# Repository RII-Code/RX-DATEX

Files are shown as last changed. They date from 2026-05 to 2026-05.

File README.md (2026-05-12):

# RX-DATEX (DATA EXCHANGE)

Perangkat IoT industrial yang berfungsi sebagai sistem gateway dan data exchange untuk komunikasi, monitoring, dan pertukaran data antar perangkat industri.

## Fitur

- Gateway Modbus RTU ↔ TCP/IP
- Pengirim data telemetry melalui jaringan 4G LTE
- Sistem monitoring device industri
- Data logger dan remote monitoring
- MQTT / HTTP data exchange
- Remote access dan konfigurasi perangkat

---

## Author

Ruang Industri Indonesia  
Industrial Automation & Robotics

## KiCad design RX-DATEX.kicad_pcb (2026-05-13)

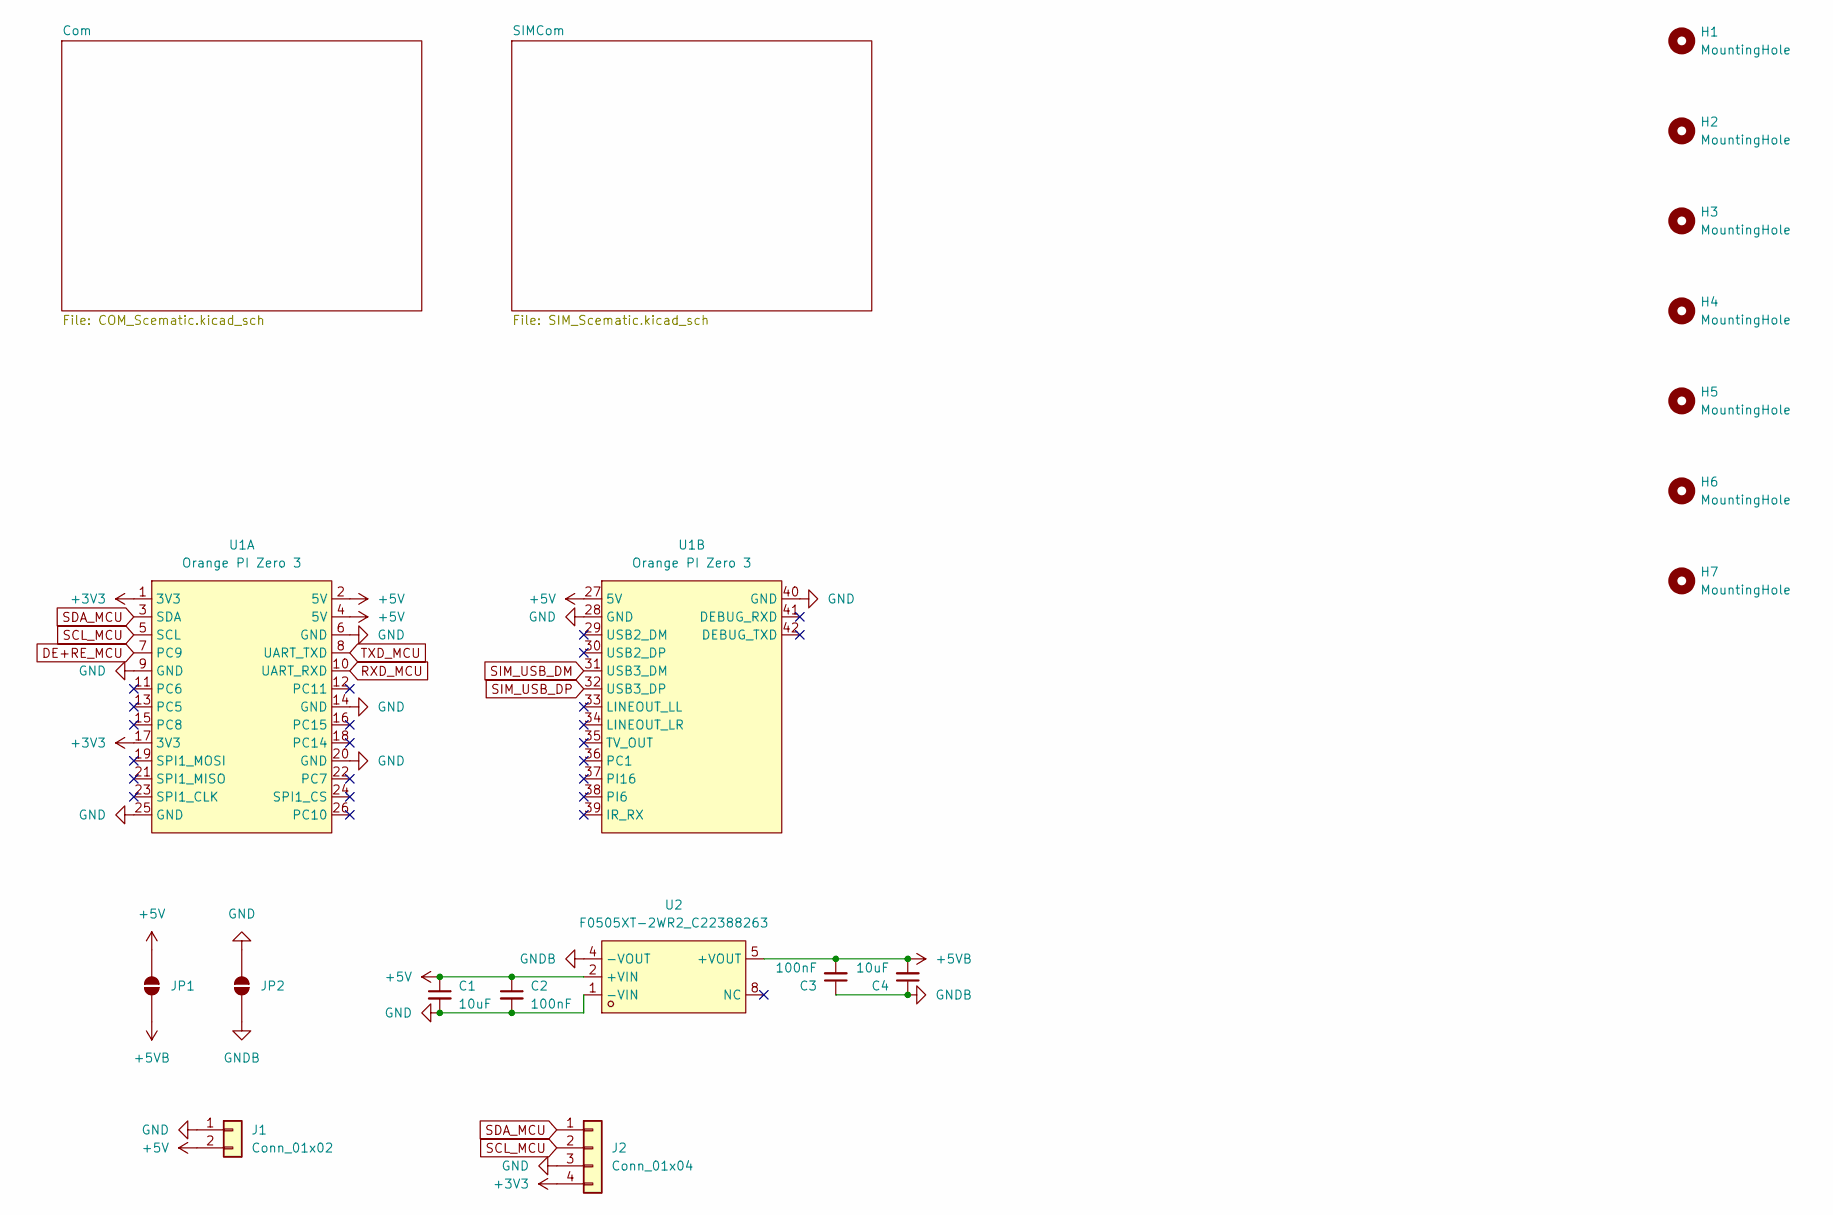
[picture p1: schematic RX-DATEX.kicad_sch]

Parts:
C1, C4: 10uF; C_0603_1608Metric
C2, C3: 100nF; C_0603_1608Metric
H1, H2, H3, H4, H5, H6, H7: MountingHole; MountingHole_3mm
J1: Conn_01x02; JST_XH_B2B-XH-A_1x02_P2.50mm_Vertical
J2: Conn_01x04; JST_XH_B4B-XH-A_1x04_P2.50mm_Vertical
JP1, JP2: SolderJumper_2_Open; SolderJumper-2_P1.3mm_Open_RoundedPad1.0x1.5mm
U1: Orange PI Zero 3; OPIZ3
U2: F0505XT-2WR2_C22388263; PWRM-SMD_FXXXXXT-2WR2; MPN F0505XT-2WR2; LCSC Part C22388263

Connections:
+3V3: J2.4, U1.1 (3V3), U1.17 (3V3); also elsewhere on the board
+5V: C1.1, C2.1, J1.2, JP1.2 (B), U1.2 (5V), U1.4 (5V), U1.27 (5V), U2.2 (+VIN); also elsewhere on the board
+5VB: C3.2, C4.2, JP1.1 (A), U2.5 (+VOUT); also elsewhere on the board
DE+RE_MCU: U1.7 (PC9); also elsewhere on the board
GND: C1.2, C2.2, J1.1, J2.3, JP2.2 (B), U1.6 (GND), U1.9 (GND), U1.14 (GND), U1.20 (GND), U1.25 (GND), U1.28 (GND), U1.40 (GND), U2.1 (-VIN); also elsewhere on the board
GNDB: C3.1, C4.1, JP2.1 (A), U2.4 (-VOUT); also elsewhere on the board
RXD_MCU: U1.10 (UART_RXD); also elsewhere on the board
SCL_MCU: J2.2, U1.5 (SCL); also elsewhere on the board
SDA_MCU: J2.1, U1.3 (SDA); also elsewhere on the board
SIM_USB_DM: U1.31 (USB3_DM); also elsewhere on the board
SIM_USB_DP: U1.32 (USB3_DP); also elsewhere on the board
TXD_MCU: U1.8 (UART_TXD); also elsewhere on the board

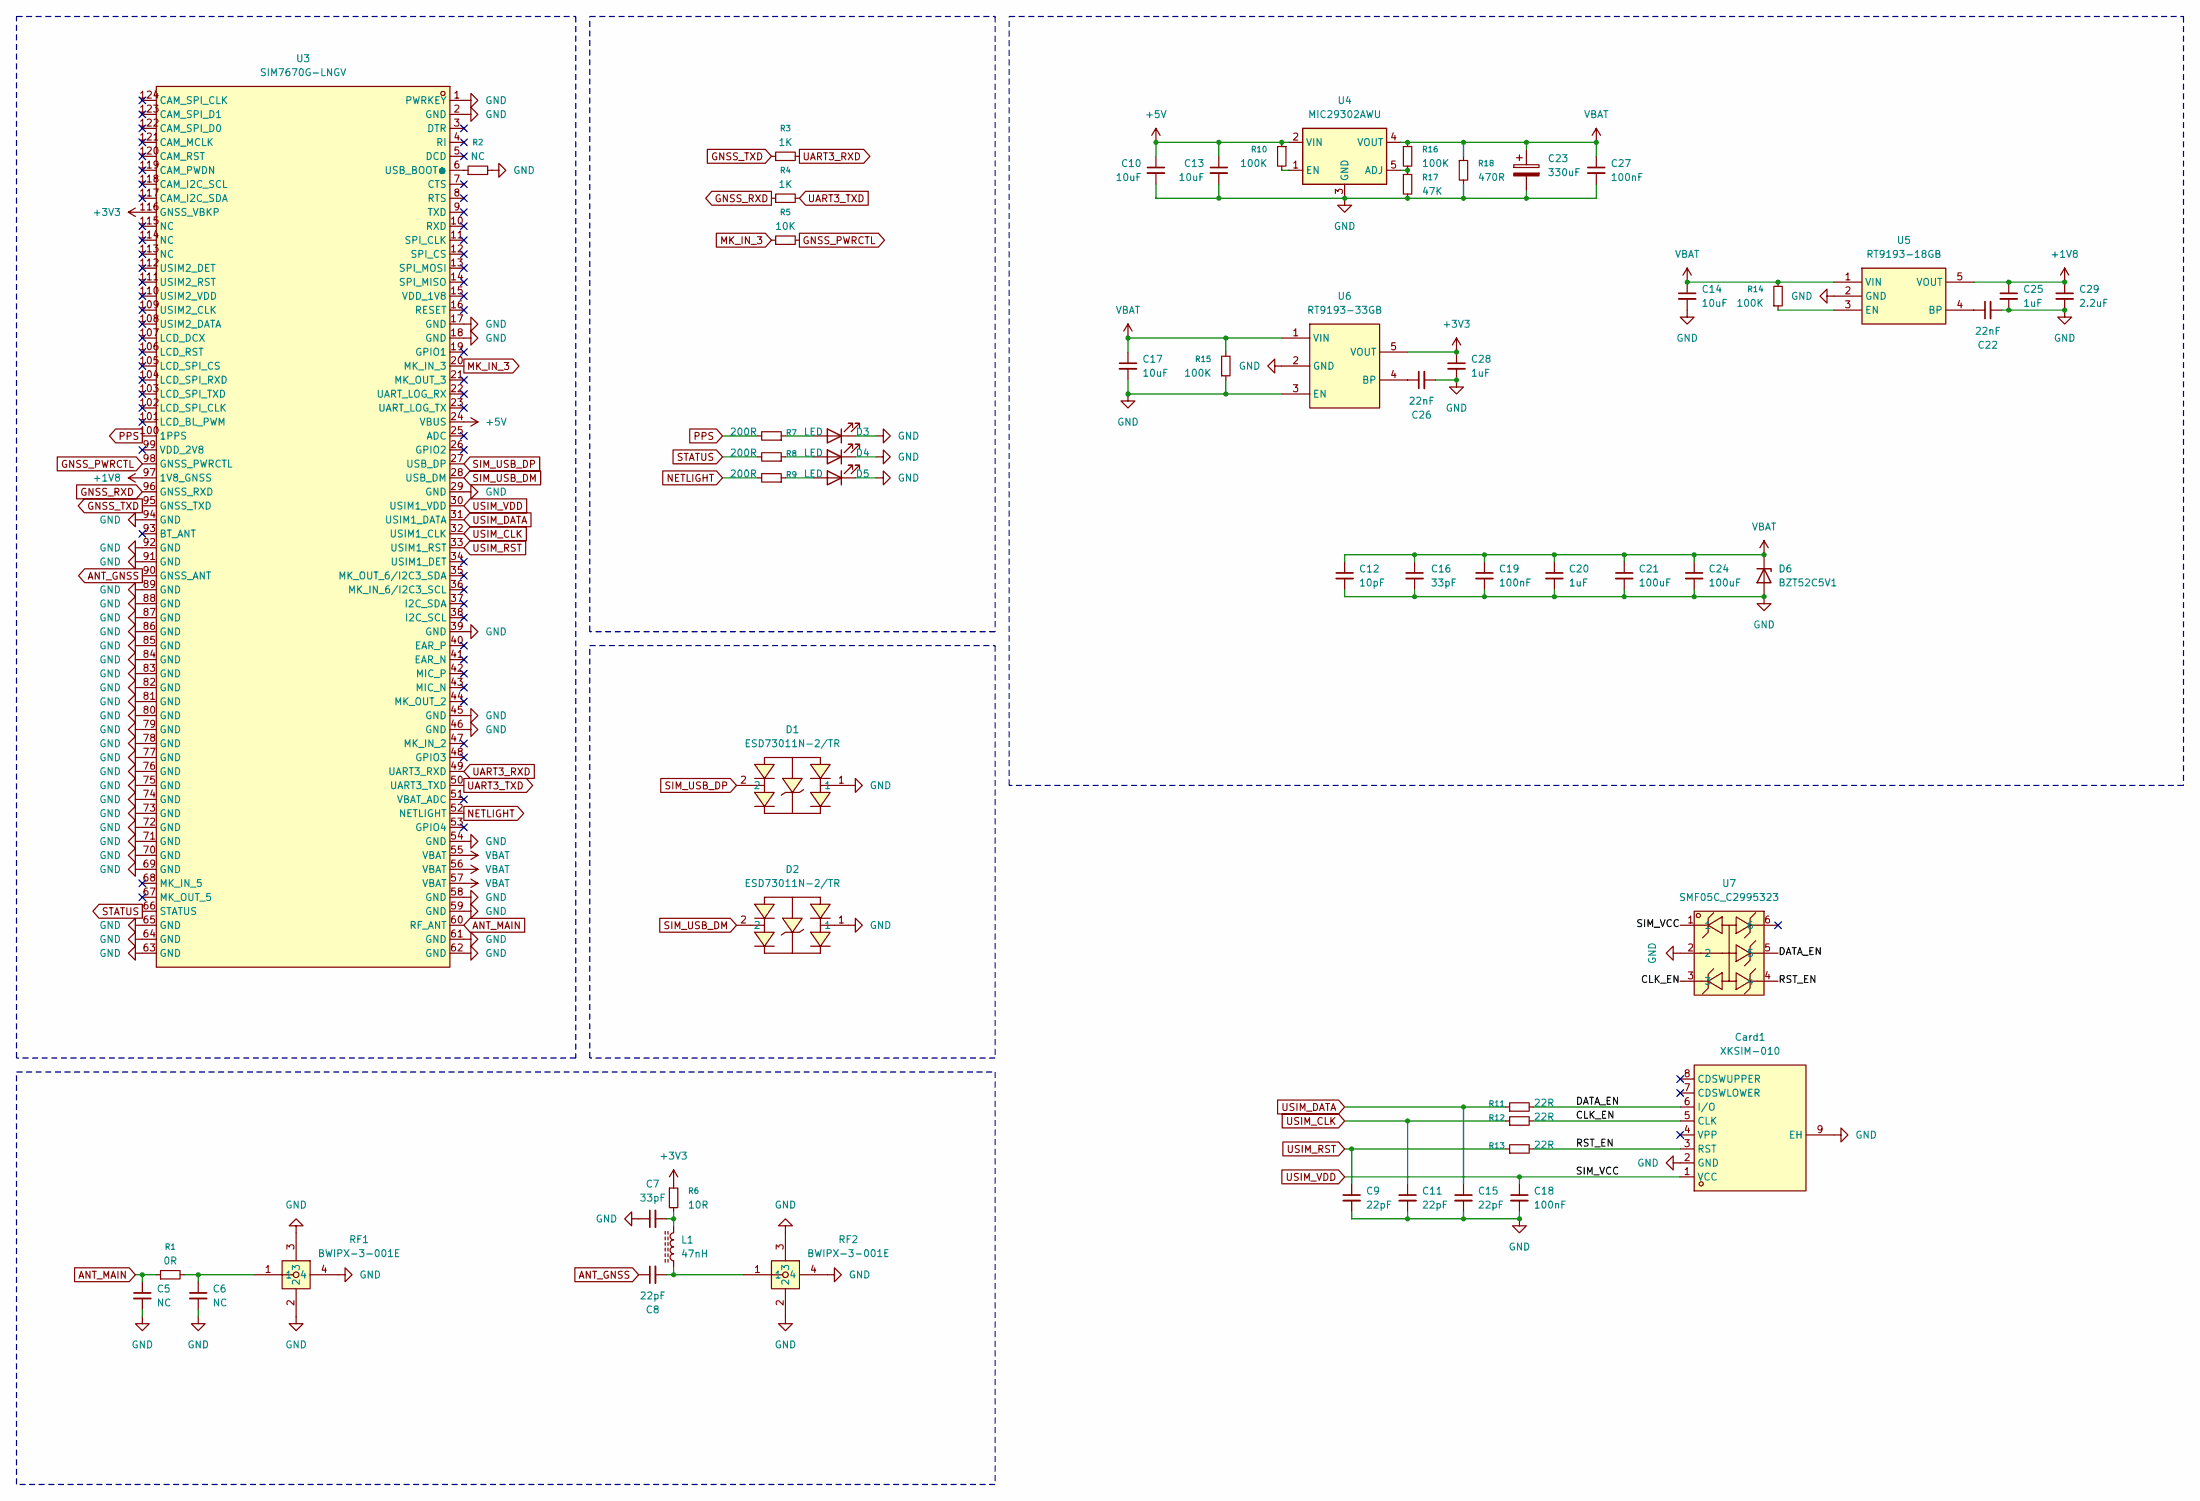
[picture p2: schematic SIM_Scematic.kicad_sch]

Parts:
C5, C6: NC; C_0603_1608Metric
C7, C16: 33pF; C_0603_1608Metric
C8, C9, C11, C15: 22pF; C_0603_1608Metric
C10, C13, C14, C17: 10uF; C_0603_1608Metric
C12: 10pF; C_0603_1608Metric
C18, C19, C27: 100nF; C_0603_1608Metric
C20, C25, C28: 1uF; C_0603_1608Metric
C21, C24: 100uF; C_0805_2012Metric
C22, C26: 22nF; C_0603_1608Metric
C23: 330uF; CP_EIA-7343-31_Kemet-D
C29: 2.2uF; C_0603_1608Metric
Card1: XKSIM-010; SIM-SMD_XKSIM-010; MPN XKSIM-010; LCSC Part C437039
D1, D2: ESD73011N-2/TR; DFN1006-2L-BI; MPN ESD73011N-2/TR; LCSC Part C506104
D3, D4, D5: LED; LED_1206_3216Metric
D6: BZT52C5V1; D_SOD-123
L1: 47nH; L_0603_1608Metric
R1: 0R; R_0603_1608Metric
R2: NC; R_0603_1608Metric
R3, R4: 1K; R_0603_1608Metric
R5: 10K; R_0603_1608Metric
R6: 10R; R_0603_1608Metric
R7, R8, R9: 200R; R_0603_1608Metric
R10, R14, R15, R16: 100K; R_0603_1608Metric
R11, R12, R13: 22R; R_0603_1608Metric
R17: 47K; R_0603_1608Metric
R18: 470R; R_0603_1608Metric
RF1, RF2: BWIPX-3-001E; IPEX-SMD_BWIPX-3-001E-1; MPN BWIPX-3-001E; LCSC Part C784400
U3: SIM7670G-LNGV; LCC-124_L24.0-W24.0-P1.0-TL; MPN SIM7670G-LNGV; LCSC Part C45935408
U4: MIC29302AWU; TO-263-5_TabPin3
U5: RT9193-18GB; SOT-23-5_L3.0-W1.7-P0.95-LS2.8-BR; MPN RT9193-18GB; LCSC Part C27416
U6: RT9193-33GB; SOT-23-5_L3.0-W1.7-P0.95-LS2.8-BL; MPN RT9193-33GB; LCSC Part C15651
U7: SMF05C_C2995323; SOT-363_L2.1-W1.3-P0.65-LS2.1-BL; MPN SMF05C; LCSC Part C2995323

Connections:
+1V8: C25.1, C29.1, U3.97 (1V8_GNSS), U5.5 (VOUT)
+3V3: C28.1, R6.1, U3.116 (GNSS_VBKP), U6.5 (VOUT); also elsewhere on the board
+5V: C10.1, C13.1, R10.1, U3.24 (VBUS), U4.2 (VIN); also elsewhere on the board
/SIMCom/CLK_EN: Card1.5 (CLK), R12.2, U7.3
/SIMCom/DATA_EN: Card1.6 (I/O), R11.2, U7.5
/SIMCom/RST_EN: Card1.3 (RST), R13.2, U7.4
ANT_GNSS: C8.1, U3.90 (GNSS_ANT)
ANT_MAIN: C5.1, R1.1, U3.60 (RF_ANT)
GND: C5.2, C6.2, C7.1, C9.2, C10.2, C11.2, C12.2, C13.2, C14.2, C15.2, C16.2, C17.2, C18.2, C19.2, C20.2, C21.2, C22.2, C23.2, C24.2, C25.2, C26.2, C27.2, C28.2, C29.2, Card1.2 (GND), Card1.9 (EH), D1.1, D2.1, D3.1 (K), D4.1 (K), D5.1 (K), D6.2 (A), R2.2, R15.1, R17.2, R18.2, RF1.2, RF1.3, RF1.4, RF2.2, RF2.3, RF2.4, U3.1 (PWRKEY), U3.2 (GND), U3.17 (GND), U3.18 (GND), U3.29 (GND), U3.39 (GND), U3.45 (GND), U3.46 (GND), U3.54 (GND), U3.58 (GND), U3.59 (GND), U3.61 (GND), U3.62 (GND), U3.63 (GND), U3.64 (GND), U3.65 (GND), U3.69 (GND), U3.70 (GND), U3.71 (GND), U3.72 (GND), U3.73 (GND), U3.74 (GND), U3.75 (GND), U3.76 (GND), U3.77 (GND), U3.78 (GND), U3.79 (GND), U3.80 (GND), U3.81 (GND), U3.82 (GND), U3.83 (GND), U3.84 (GND), U3.85 (GND), U3.86 (GND), U3.87 (GND), U3.88 (GND), U3.89 (GND), U3.91 (GND), U3.92 (GND), U3.94 (GND), U4.3 (GND), U5.2 (GND), U6.2 (GND), U6.3 (EN), U7.2; also elsewhere on the board
GNSS_PWRCTL: R5.2, U3.98 (GNSS_PWRCTL)
GNSS_RXD: R4.1, U3.96 (GNSS_RXD)
GNSS_TXD: R3.1, U3.95 (GNSS_TXD)
MK_IN_3: R5.1, U3.20 (MK_IN_3)
NETLIGHT: R9.2, U3.52 (NETLIGHT)
unnamed: C6.1, R1.2, RF1.1
unnamed: C7.2, L1.2, R6.2
unnamed: C8.2, L1.1, RF2.1
unnamed: D3.2 (A), R7.1
unnamed: D4.2 (A), R8.1
unnamed: D5.2 (A), R9.1
unnamed: R2.1, U3.6 (USB_BOOT●)
unnamed: R16.2, R17.1, U4.5 (ADJ)
unnamed: R10.2, U4.1 (EN)
unnamed: C22.1, U5.4 (BP)
unnamed: R14.1, U5.3 (EN)
unnamed: C26.1, U6.4 (BP)
PPS: R7.2, U3.100 (1PPS)
SIM_USB_DM: D2.2, U3.28 (USB_DM); also elsewhere on the board
SIM_USB_DP: D1.2, U3.27 (USB_DP); also elsewhere on the board
STATUS: R8.2, U3.66 (STATUS)
UART3_RXD: R3.2, U3.49 (UART3_RXD)
UART3_TXD: R4.2, U3.50 (UART3_TXD)
USIM_CLK: C11.1, R12.1, U3.32 (USIM1_CLK)
USIM_DATA: C15.1, R11.1, U3.31 (USIM1_DATA)
USIM_RST: C9.1, R13.1, U3.33 (USIM1_RST)
USIM_VDD: C18.1, Card1.1 (VCC), U3.30 (USIM1_VDD), U7.1
VBAT: C12.1, C14.1, C16.1, C17.1, C19.1, C20.1, C21.1, C23.1, C24.1, C27.1, D6.1 (K), R14.2, R15.2, R16.1, R18.1, U3.55 (VBAT), U3.56 (VBAT), U3.57 (VBAT), U4.4 (VOUT), U5.1 (VIN), U6.1 (VIN)

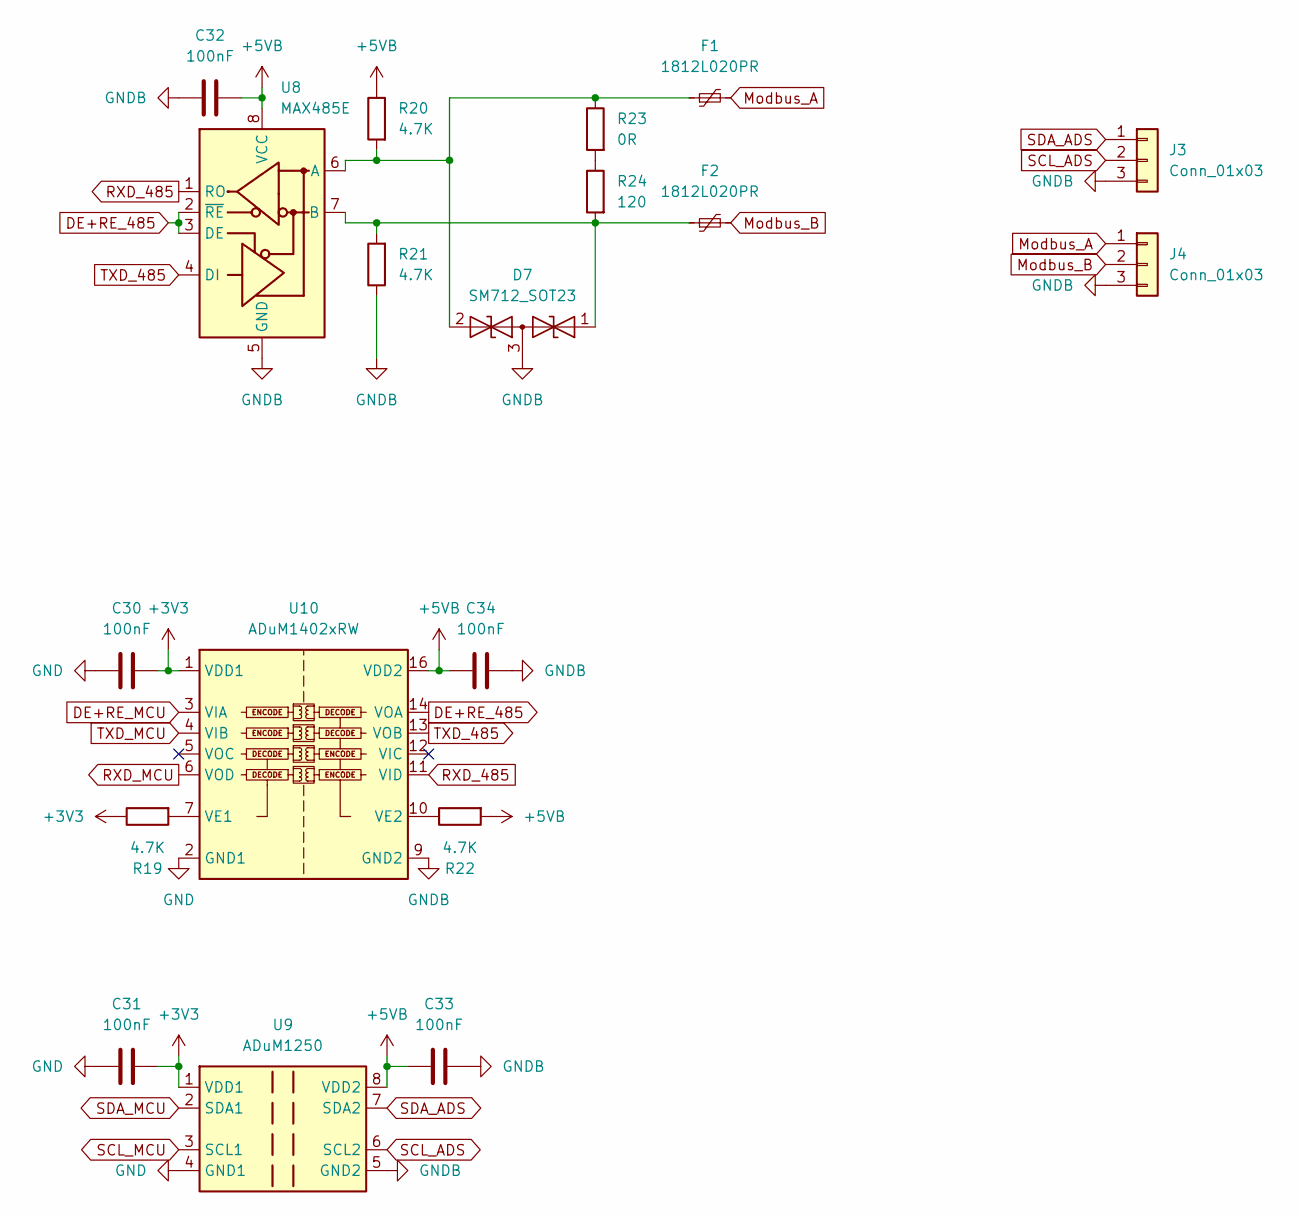
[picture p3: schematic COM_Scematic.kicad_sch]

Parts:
C30, C31, C32, C33, C34: 100nF; C_0603_1608Metric_Pad1.08x0.95mm_HandSolder
D7: SM712_SOT23; SOT-23
F1, F2: 1812L020PR; Fuse_1812_4532Metric
J3, J4: Conn_01x03; PhoenixContact_MC_1,5_3-G-3.81_1x03_P3.81mm_Horizontal
R19, R20, R21, R22: 4.7K; R_0603_1608Metric_Pad0.98x0.95mm_HandSolder
R23: 0R; R_0603_1608Metric_Pad0.98x0.95mm_HandSolder
R24: 120; R_0603_1608Metric_Pad0.98x0.95mm_HandSolder
U8: MAX485E; SOIC-8_3.9x4.9mm_P1.27mm
U9: ADuM1250; SOIC-8_3.9x4.9mm_P1.27mm
U10: ADuM1402xRW; SOIC-16W_7.5x10.3mm_P1.27mm

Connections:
+3V3: C30.2, C31.2, R19.1, U9.1 (VDD1), U10.1 (VDD1); also elsewhere on the board
+5VB: C32.2, C33.2, C34.2, R20.1, R22.2, U8.8 (VCC), U9.8 (VDD2), U10.16 (VDD2); also elsewhere on the board
DE+RE_485: U8.2 (~RE), U8.3 (DE), U10.14 (VOA)
DE+RE_MCU: U10.3 (VIA); also elsewhere on the board
GND: C30.1, C31.1, U9.4 (GND1), U10.2 (GND1), U10.8 (GND1); also elsewhere on the board
GNDB: C32.1, C33.1, C34.1, D7.3 (common), J3.3, J4.3, R21.1, U8.5 (GND), U9.5 (GND2), U10.9 (GND2), U10.15 (GND2); also elsewhere on the board
Modbus_A: F1.2, J4.1
Modbus_B: F2.2, J4.2
unnamed: D7.1 (A1), F2.1, R21.2, R24.2, U8.7 (B)
unnamed: D7.2 (A2), F1.1, R20.2, R23.1, U8.6 (A)
unnamed: R23.2, R24.1
unnamed: R19.2, U10.7 (VE1)
unnamed: R22.1, U10.10 (VE2)
RXD_485: U8.1 (RO), U10.11 (VID)
RXD_MCU: U10.6 (VOD); also elsewhere on the board
SCL_ADS: J3.2, U9.6 (SCL2)
SCL_MCU: U9.3 (SCL1); also elsewhere on the board
SDA_ADS: J3.1, U9.7 (SDA2)
SDA_MCU: U9.2 (SDA1); also elsewhere on the board
TXD_485: U8.4 (DI), U10.13 (VOB)
TXD_MCU: U10.4 (VIB); also elsewhere on the board

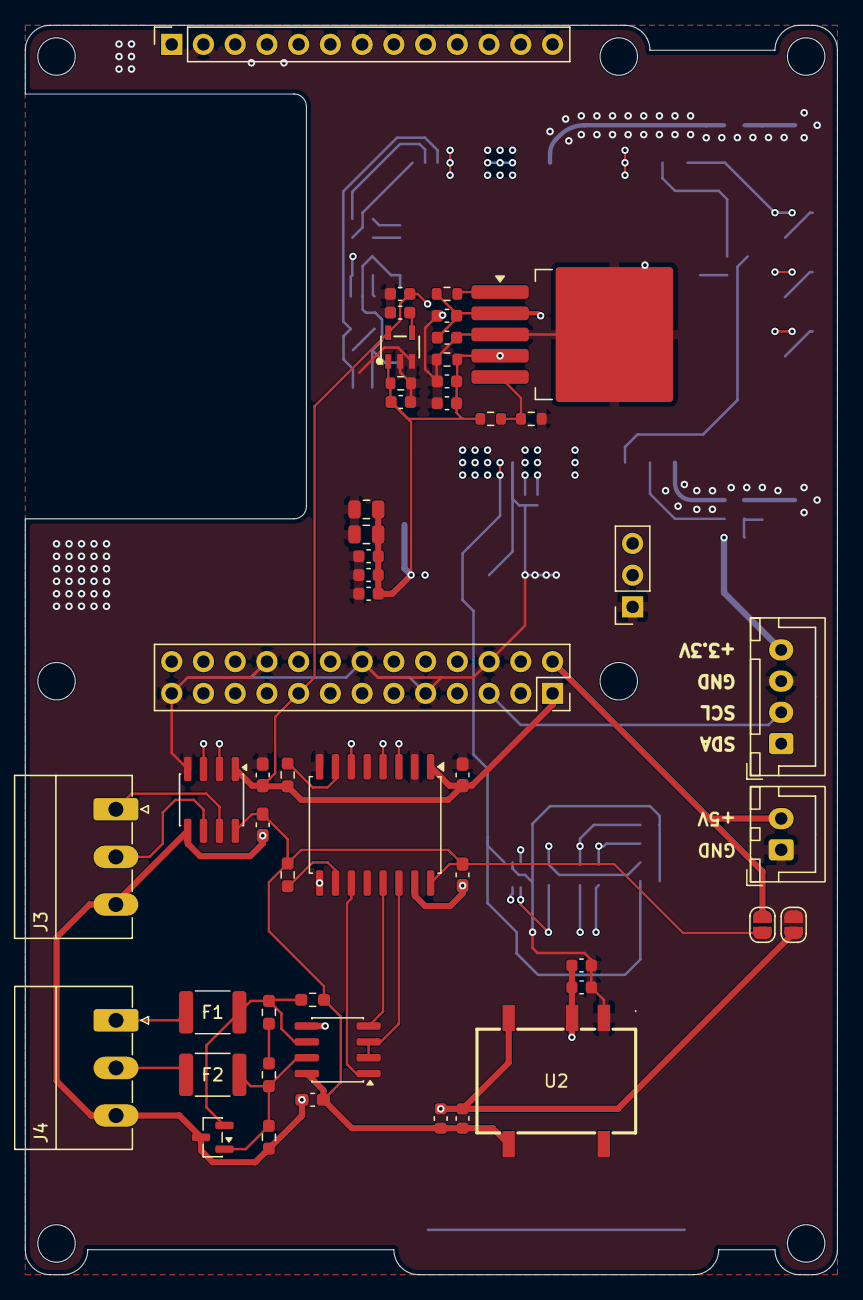
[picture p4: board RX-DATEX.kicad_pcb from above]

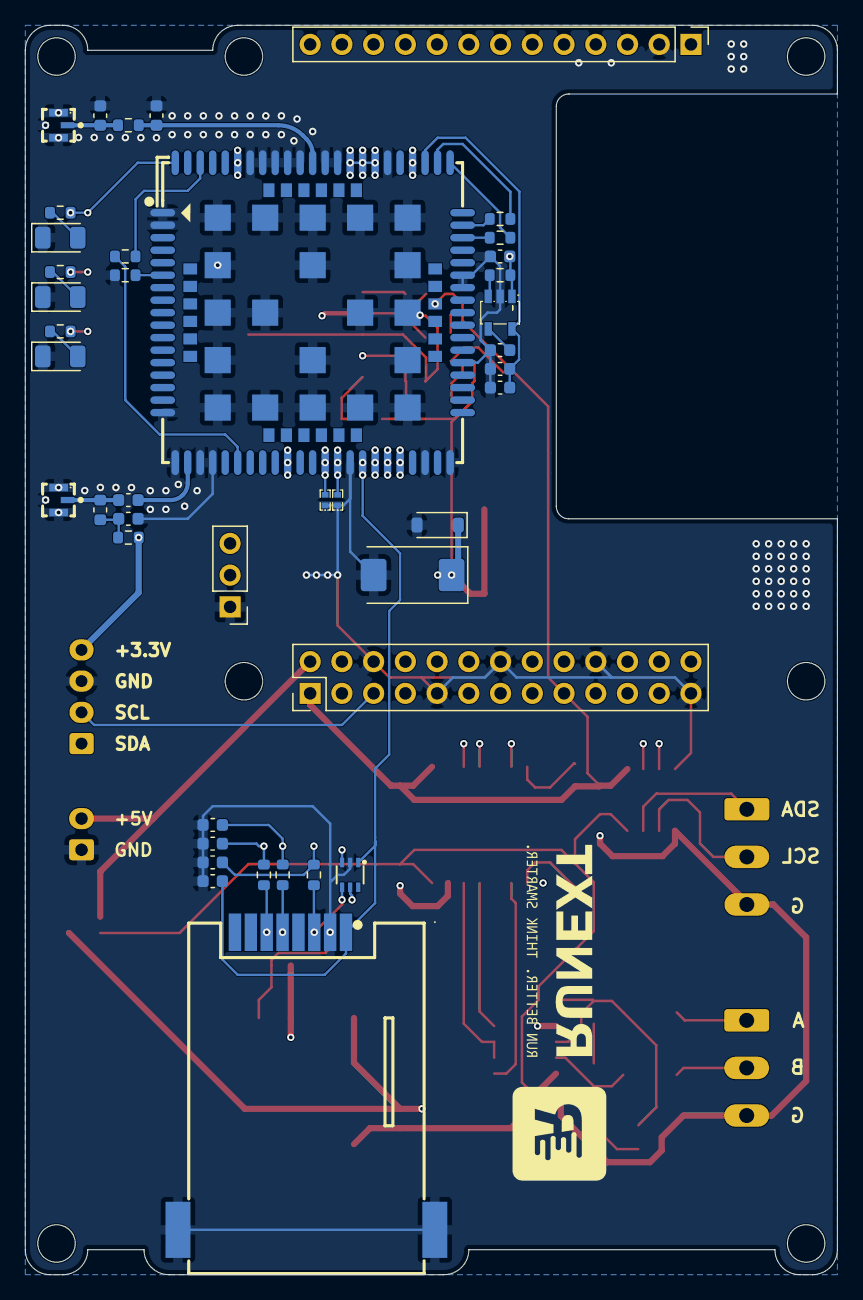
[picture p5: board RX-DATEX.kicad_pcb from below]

Board: 4 copper layers, 65.0 x 100.0 mm, 94 parts (40 on the bottom side), 56 nets.
